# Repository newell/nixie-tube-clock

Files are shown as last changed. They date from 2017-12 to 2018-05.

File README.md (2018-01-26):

# nixie-tube-clock
### Nixie Tube Clock

**PROJECT STATUS: Boards just arrived from fab.  Next step is to solder on all the components and test the design.**

Nixie Tube Clock with wireless NTP syncing.

This project is split into three boards.  One for the nixie clock display, one for the shift registers and high voltage transistors to drive the nixies, and a control board that has the MCU and power supplies for the entire board (including the high voltage needed by the nixie tubes).

Here is a **photo mode** png of each of the boards:

* **DISPLAY**

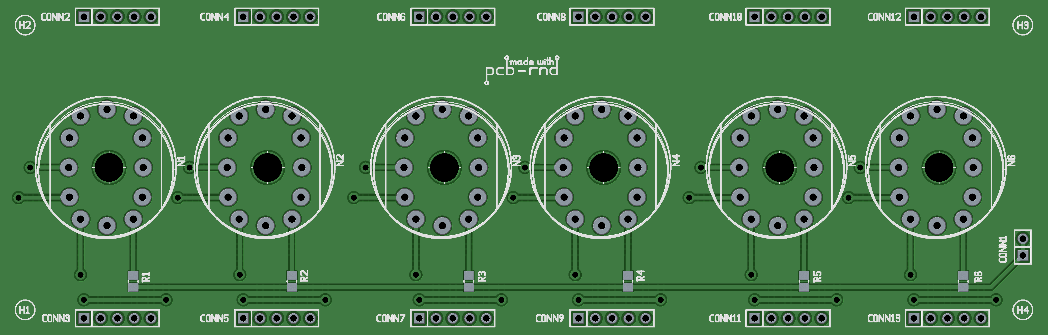
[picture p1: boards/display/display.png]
Nixie Tube Clock display board top layer


* **DRIVER**

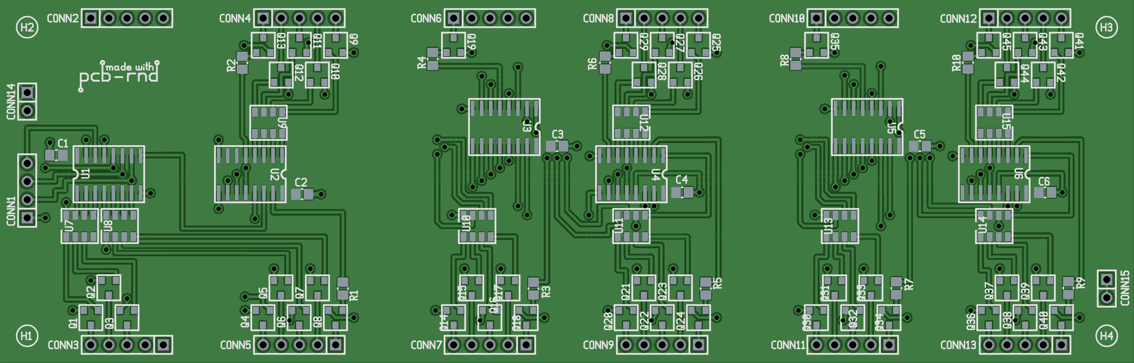
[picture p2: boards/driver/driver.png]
Nixie Tube Clock driver board top layer


* **CONTROLLER**

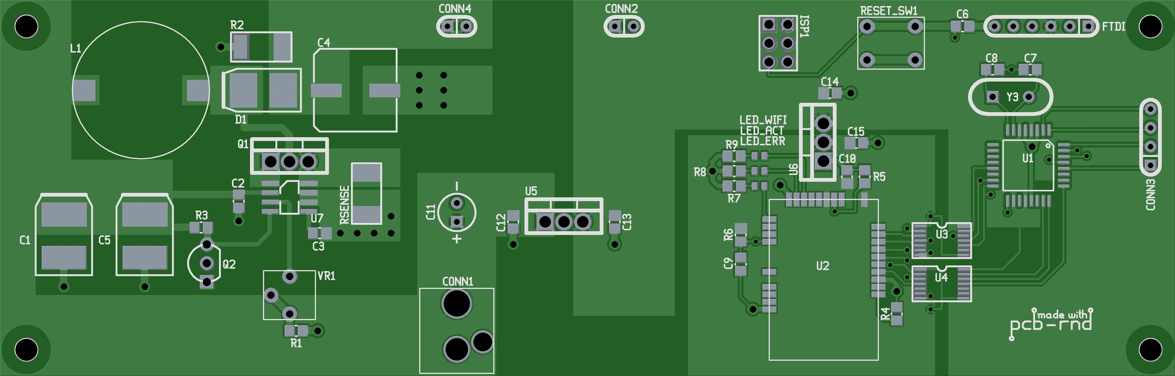
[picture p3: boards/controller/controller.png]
Nixie Tube Clock controller board top layer


Here is an actual photo of the boards after coming back from the fab:

* **ALL BOARDS**

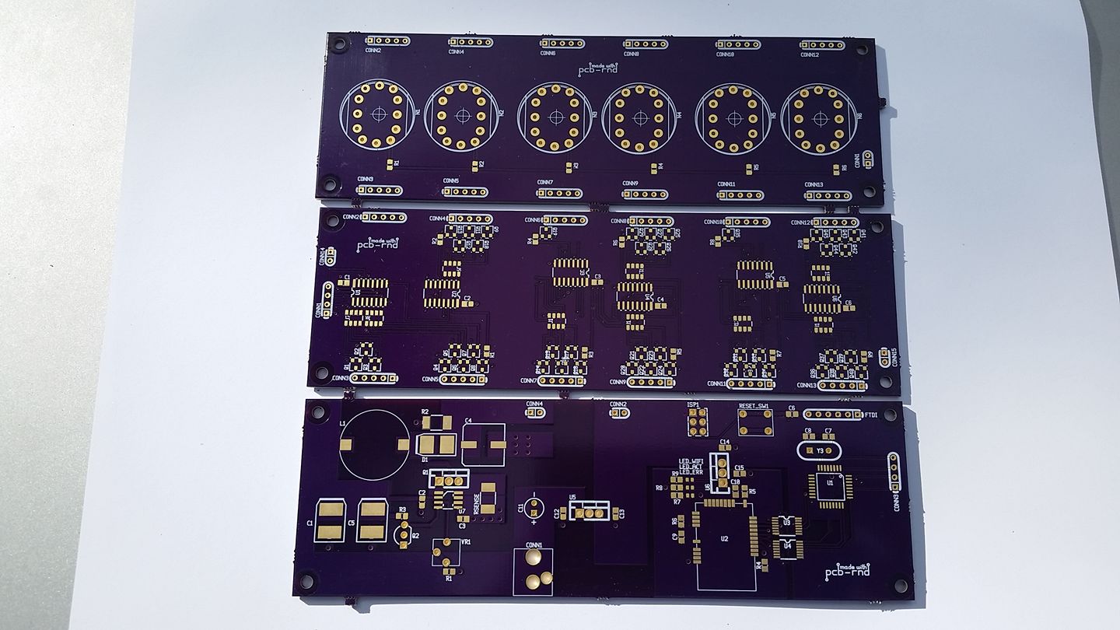
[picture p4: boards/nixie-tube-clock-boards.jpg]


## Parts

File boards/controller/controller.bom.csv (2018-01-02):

device | value | footprint | quantity | refdes | digikey PN
7805 | unknown | TO220W | 1 | U5 | NCP7805TGOS-ND
7805 | unknown | TO220W | 1 | U6 | 497-1485-5-ND
CAPACITOR | 0.001uF | 0805 | 1 | C9 | 311-1122-1-ND
CAPACITOR | 0.1uF | 0805 | 6 | C2 C3 C6 C10 C12 C14 | 311-3562-1-ND
CAPACITOR | 10uF | 0805 | 2 | C13 C15 | 311-1460-1-ND
CAPACITOR | 22pF | 0805 | 2 | C7 C8 | 311-1103-1-ND
CONNECTOR_2 | unknown | SIP2 | 2 | CONN2 CONN4 | 732-5315-ND
CONNECTOR_4 | unknown | SIP4 | 1 | CONN3 | 732-5317-ND
CONNECTOR_6 | unknown | SIP6 | 1 | FTDI | 732-5319-ND
CRYSTAL | 16MHz | HC49 | 1 | Y3 | XC1925-ND
DIODE | ES2F | DO214 | 1 | D1 | ES2F-E3/52TGICT-ND
HEADER6 | unknown | CON_HDR-254P-3C-2R-6N__Molex_8624-Series | 1 | ISP1 | 732-5295-ND
HOLE | unknown | hole_3mm | 4 | H1 H2 H3 H4 | N/A
INDUCTOR | 100uH | B82479A | 1 | L1 | 495-2703-1-ND
LED | unknown | 0603 | 1 | LED_ACT | 754-1541-1-ND
LED | unknown | 0603 | 1 | LED_ERR | 754-1544-1-ND
LED | unknown | 0603 | 1 | LED_WIFI | 754-1547-1-ND
MICROCONTROLLER | ATmega328_TQFP | TQFP32_7 | 1 | U1 | ATMEGA328P-AURCT-ND
NMOS_TRANSISTOR | IRF840 | TO220W | 1 | Q1 | IRF840APBF-ND
NPN_TRANSISTOR | 2N7000 | TO92 | 1 | Q2 | 2N7000TACT-ND
POLARIZED_CAPACITOR | 100uF/35V | EIA7343 | 1 | C1 | 478-6066-1-ND
POLARIZED_CAPACITOR | 10uF/250V | NICHICON_WT_CAP_10_10 | 1 | C4 | PCE3432CT-ND
POLARIZED_CAPACITOR | 10uF/25V | EIA7343 | 1 | C5 | 478-1775-1-ND
POLARIZED_CAPACITOR | 47uF | RCY100P | 1 | C11 | N/A - in stock
PWRJACK | unknown | PJ044A | 1 | CONN1 | CP-044A-ND
RESISTOR | 0.05 | 2512 | 1 | RSENSE | P50MCT-ND
RESISTOR | 1k | 0805 | 3 | R7 R8 R9 | 311-1.00KCRCT-ND
RESISTOR | 10k | 0805 | 1 | R1 | 311-10.0KCRCT-ND
RESISTOR | 100k | 0805 | 4 | R3 R4 R5 R6 | 311-100KCRCT-ND
RESISTOR | 1M5/220V+ | 2512 | 1 | R2 | A121175CT-ND
SWITCH_PUSHBUTTON_NO | unknown | B3F-1022 | 1 | RESET_SW1 | SW403-ND
TXB0104PWR | unknown | TSSOP14 | 2 | U3 U4 | 296-21929-1-ND
VARIABLE_RESISTOR | 3362P | bourns_3362P | 1 | VR1 | 3362P-502LF-ND
WIDEBAND_AMPLIFIER | MAX1771 | SO8 | 1 | U7 | MAX1771ESA+-ND
WIRELESS_IOT | ATWINC1500 | ATWINC1500-MR210 | 1 | U2 | ATWINC1500-MR210PA-ND

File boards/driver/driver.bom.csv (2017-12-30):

device | value | footprint | quantity | refdes | digikey PN
74595 | unknown | SO16 | 6 | U1 U2 U3 U4 U5 U6 | 296-14857-1-ND
CAPACITOR | 0.1uF | 0805 | 6 | C1 C2 C3 C4 C5 C6 | 311-3562-1-ND
CONNECTOR_2 | unknown | SIP2 | 2 | CONN14 CONN15 | 732-5315-ND
CONNECTOR_4 | unknown | SIP4 | 1 | CONN1 | 732-5317-ND
CONNECTOR_5 | unknown | SIP5 | 12 | CONN2 CONN3 CONN4 CONN5 CONN6 CONN7 CONN8 CONN9 CONN10 CONN11 CONN12 CONN13 | 732-5318-ND
HOLE | unknown | hole_3mm | 4 | H1 H2 H3 H4
NPN_TRANSISTOR | unknown | SOT23 | 45 | Q1 Q2 Q3 Q4 Q5 Q6 Q7 Q8 Q9 Q10 Q11 Q12 Q13 Q14 Q15 Q16 Q17 Q18 Q19 Q20 Q21 Q22 Q23 Q24 Q25 Q26 Q27 Q28 Q29 Q30 Q31 Q32 Q33 Q34 Q35 Q36 Q37 Q38 Q39 Q40 Q41 Q42 Q43 Q44 Q45 | MMBTA42FSCT-ND
RESISTOR | 47 | 0805 | 10 | R1 R2 R3 R4 R5 R6 R7 R8 R9 R10 | 311-47.0CRCT-ND
RESISTOR_ARRAY | 744C083470JP | CTS_744C_08 | 9 | U7 U8 U9 U10 U11 U12 U13 U14 U15 | 744C083470JPCT-ND

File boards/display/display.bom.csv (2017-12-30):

device | value | footprint | quantity | refdes | digikey PN
CONNECTOR_2 | unknown | SIP2 | 1 | CONN1 | 732-5315-ND
CONNECTOR_5 | unknown | SIP5 | 12 | CONN2 CONN3 CONN4 CONN5 CONN6 CONN7 CONN8 CONN9 CONN10 CONN11 CONN12 CONN13 | 732-5318-ND
HOLE | unknown | hole_3mm | 4 | H1 H2 H3 H4 | N/A
NIXIE_TUBE | IN-12A | IN-12 | 6 | N1 N2 N3 N4 N5 N6 | N/A - in stock
RESISTOR | 15k | 0805 | 6 | R1 R2 R3 R4 R5 R6 | 311-15.0KCRCT-ND

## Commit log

2017-11-28 Add display schematics and project file.
    [display.sch]
2017-11-28 Add display pcb layout and gsch2pcb created files.
2017-11-29 Update .gitignore, display pcb, and add photo of board.
2017-12-04 Initial driver.sch commit, update .gitignore
    [driver.sch]
2017-12-05 Initial controller.sch commit.
    [controller.sch]
2017-12-07 Add project file for controller schematic.
2017-12-07 Add more values and footprints to symbols in controller.sch
    [controller.sch]
2017-12-13 Update controller schematic.
    [controller.sch]
2017-12-14 Finish adding footprint attributes to schematic.
    [controller.sch]
2017-12-14 Add footprints for all symbols in controller schematic.
    [controller.sch]
2017-12-14 Add controller board directory and initial controller board files.
2017-12-14 Update controller board with new footprints.
2017-12-19 Update controller schematic. Fix some netlist issues, add symbols for the mounting holes.
    [controller.sch]
2017-12-19 Update controller layout with new netlist changes from schematic. Started laying out the 12V to 150-220V section.
2017-12-19 Update driver schematic.
    [driver.sch]
2017-12-20 Finish driver schematic.
    [driver.sch]
2017-12-20 Create initial pcb layout for driver board.
2017-12-23 Include hole symbols in display schematic.
    [display.sch]
2017-12-23 Update display pcb with new footprints for holes. Update photo.
2017-12-23 Update footprints for mounting holes in driver schematics.
    [driver.sch]
2017-12-23 Update driver pcb.
2017-12-26 Update driver schematic to match display connectors.
    [driver.sch]
2017-12-26 Update driver pcb with new schematic and layout changes.
2017-12-27 Update and finish layout for driver board.
2017-12-27 Add photo for driver board.
2017-12-27 Update mounting hole footprints for controller schematic.
    [controller.sch]
2017-12-27 Update controller schematic. Include walwart jack for 12V input.
    [controller.sch]
2017-12-27 Update controller board layout with schematic changes.
2017-12-28 Finish boost voltage section for controller board.
2017-12-29 Update controller schecmatic with new switch symbol.
    [controller.sch]
2017-12-29 Update controller board and started using pcb-rnd for board layout (no longer can use pcb to open file).
2017-12-29 Add controller board photo.
2017-12-29 Update controller board silk positioning.
2017-12-29 Add BOM for controller board.
    [controller.bom.csv]
2017-12-29 Change footprint for MAX1771 and power jack.
    [controller.sch]
2017-12-30 Change crystal footprint from HC49 to HC49U.
    [controller.sch]
2017-12-30 Update controller board with new footprint for power jack, MAX 1771, and crystal.
2017-12-30 Update controller board photo.
2017-12-30 Reposition crystal and it's capacitors to accomadate new footprint size.
2017-12-30 Add display board BOM.
    [display.bom.csv]
2017-12-30 Update driver schematic with new values for resistors and capacitors.
    [driver.sch]
2017-12-30 Add BOM for driver board.
    [driver.bom.csv]
2017-12-30 Update boards to have 'made with pcb-rnd' silk logos. Update photos.
2018-01-02 Update controller BOM.
    [controller.bom.csv]
2018-01-14 Add postscript file for controller board.
2018-01-14 Add postscript file for display board.
2018-01-14 Add postscript file for driver board.
2018-01-15 Move silk for 6 pin header.
2018-01-15 Add gerbers for controller board.
    [controller.bottom.gbr, controller.bottommask.gbr, controller.fab.gbr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]
2018-01-15 Swap ground and bottom layers in controller board layers. Update gerbers.
    [controller.bottom.gbr, controller.bottommask.gbr, controller.bottompaste.gbr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]
2018-01-15 Add gerbers for display board.
    [display.bottom.gbr, display.bottommask.gbr, display.bottompaste.gbr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]
2018-01-15 Swap ground and bottom layers in driver board.
2018-01-15 Add driver board gerbers.
    [driver.bottom.gbr, driver.bottommask.gbr, driver.bottompaste.gbr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]
2018-01-15 Update postscript file for display board.
2018-01-15 Update postscript file for driver board.
2018-01-26 Add photo of boards before soldering on components.
2018-01-26 Renamed photo of boards.
2018-03-18 Rename current layouts so that we know these boards were used with pcb-rnd.
2018-03-18 Update schematics to have JUMPER# footprints instead of faulty SIP# footprints.
    [controller.sch, display.sch, driver.sch]
2018-03-18 Create gEDA pcb files for pcb-rnd layouts.
2018-03-18 Update gEDA PCB layouts with new schematic updates (JUMPER footprints).
2018-03-18 Update thermals for controller and driver gEDA PCB layouts.
2018-03-18 Re-route HV_SHDN net to Q2 from pin 10 on ATMEGA. Move R2 closer to trimmerpot to try and fix EMI pickup issues.
2018-05-14 Re-route disply board. This was needed because bottom connectors were flipped for driver board.
2018-05-14 Add drill holes for nixie tubes and update display.png.
2018-05-14 Update driver layout to have slightly larger vias for possible home etching. Create new png and rename some files.
